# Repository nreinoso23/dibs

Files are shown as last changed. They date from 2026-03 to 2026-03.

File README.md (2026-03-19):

# Dibs — Smart Study Room Kiosk System

> **Automated room reservation management with real-time occupancy verification for NYU Dibner Library**

Dibs is a distributed IoT room management system that solves a simple but persistent problem: **nobody knows how many study rooms are actually being used at any given time.** Rooms get ghost-booked, stolen by people who never reserved, and there's zero accountability for no-shows.

This system pairs an outer kiosk (Raspberry Pi 5 with touchscreen, sensors, and physical buttons) with an inner occupancy module (ESP32-S3 with camera and LCD), all synchronized through Google Calendar API to a web booking interface — delivering real-time room status, automated check-in enforcement, and walk-in booking at **~$167 per unit** versus $749–$800+ for enterprise competitors.

Built as a Semester Long Design Project (SLDP) at NYU Tandon School of Engineering.

<p align="center">
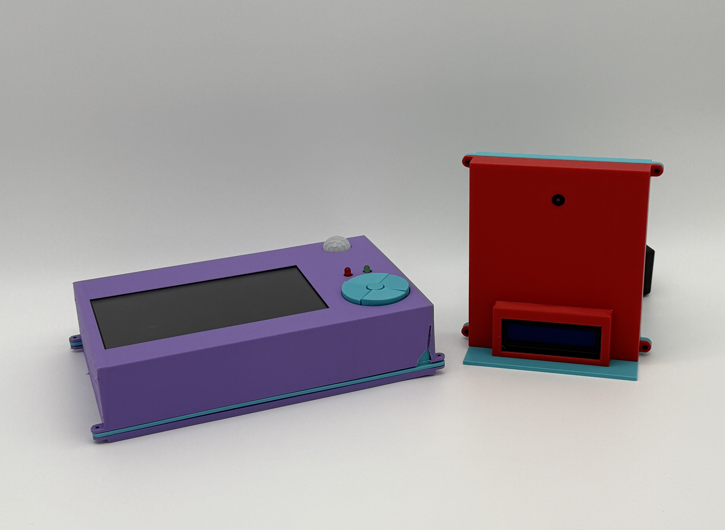
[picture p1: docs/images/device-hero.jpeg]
Dibs Kiosk System
  
</p>

<p align="center">
  <a href="https://youtu.be/KSitBOF_cG8">📺 Watch the full demo video</a>
</p>

---

## Table of Contents

- [Features](#features)
- [System Architecture](#system-architecture)
- [Hardware](#hardware)
- [Software Components](#software-components)
- [Room State Machine](#room-state-machine)
- [Tech Stack](#tech-stack)
- [Project Structure](#project-structure)
- [Setup & Installation](#setup--installation)
- [Configuration](#configuration)
- [How It Works](#how-it-works)
- [Competitive Analysis](#competitive-analysis)
- [Design Decisions & Tradeoffs](#design-decisions--tradeoffs)
- [Lessons Learned](#lessons-learned)
- [Future Improvements](#future-improvements)
- [Team](#team)

---

## Features

- **Real-time reservation display** — Shows current and upcoming bookings synced with Google Calendar
- **Walk-in booking** — 2-tap booking with dynamic duration limits based on next reservation and library hours
- **Check-in enforcement** — 10-minute check-in window with N-number authentication; no-shows auto-canceled
- **Occupancy verification** — Face detection via ESP32-CAM confirms room is actually in use
- **Physical button navigation** — Full GPIO-driven interface for accessible, touchscreen-free operation
- **Motion-activated display** — PIR sensor wakes screen on approach, sleeps after 30 seconds of inactivity
- **LED status indicators** — Green (available) / Red (occupied) visible from down the hallway
- **Context-aware LCD messaging** — Inner room display adapts messages based on face detection + room state
- **Adaptive polling** — Dynamic refresh rates (5–30s) based on proximity to check-in windows
- **Web + kiosk sync** — Bidirectional: bookings from either interface appear on both instantly

<p align="center">
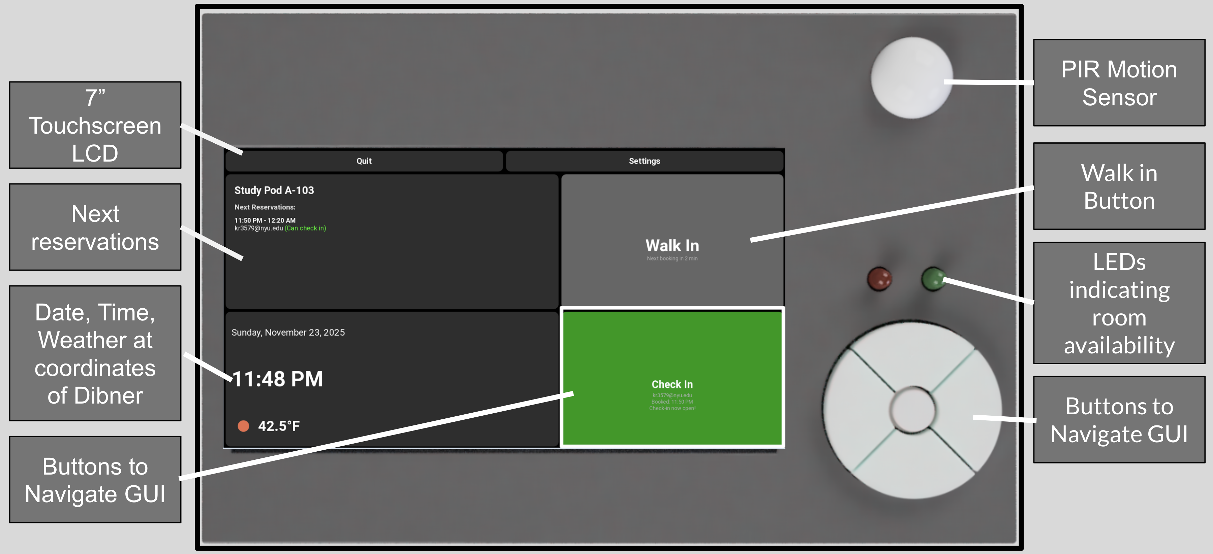
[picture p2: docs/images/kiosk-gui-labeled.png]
Kiosk GUI Interface
  
  <br>
  <em>Kiosk touchscreen interface with labeled components</em>
</p>

---

## System Architecture

```
┌──────────────────────────────────────────────────────────────────────┐
│                        RASPBERRY PI 5 (Outer Kiosk)                  │
│                                                                      │
│  ┌──────────────────┐  ┌──────────────────┐  ┌───────────────────┐  │
│  │  Main Kiosk GUI  │  │  Flask API Server │  │  Face Detection + │  │
│  │    (app.py)      │◄─│  (kiosk_api_     │◄─│  LCD Controller   │  │
│  │                  │  │   server.py)      │  │  (pi_cam_smart_  │  │
│  │  Kivy Framework  │  │                  │  │   lcd.py)         │  │
│  │  GPIO Buttons    │  │  /api/room_status │  │                  │  │
│  │  PIR Sensor      │  │  /api/health     │  │  OpenCV + cvzone  │  │
│  │  LED Control     │  │  /api/schedule   │  │  Headless mode    │  │
│  └──────────────────┘  └──────────────────┘  └────────┬──────────┘  │
│                                                        │             │
└────────────────────────────────────────────────────────┼─────────────┘
                                                         │
                                                   WiFi (HTTP)
                                                         │
┌────────────────────────────────────────────────────────┼─────────────┐
│                      ESP32-S3 CAM (Inner Module)       │             │
│                                                        │             │
│  ┌─────────────────────────────────────────────────────┘            │
│  │                                                                  │
│  │  Arduino Sketch (Station Mode)                                   │
│  │  - MJPEG Video Streaming (port 81)                               │
│  │  - HTTP endpoint for LCD text control (/lcd)                     │
│  │  - I2C 16x2 LCD Display Driver                                   │
│  │  - Connects to existing WiFi (not AP mode)                       │
│  │                                                                  │
└──────────────────────────────────────────────────────────────────────┘
                                    │
                            Google Calendar API
                                    │
┌───────────────────────────────────┼──────────────────────────────────┐
│                  Web Booking Interface (nyu-dibner-bookings.onrender.com)      │
│                  Built by Kashvi Rungta                                       │
│                  - Remote reservations                                        │
│                  - Same calendar as single source of truth                    │
└──────────────────────────────────────────────────────────────────────┘
```

---

## Hardware

### Outer Device (Mounted outside room door)

<p align="center">
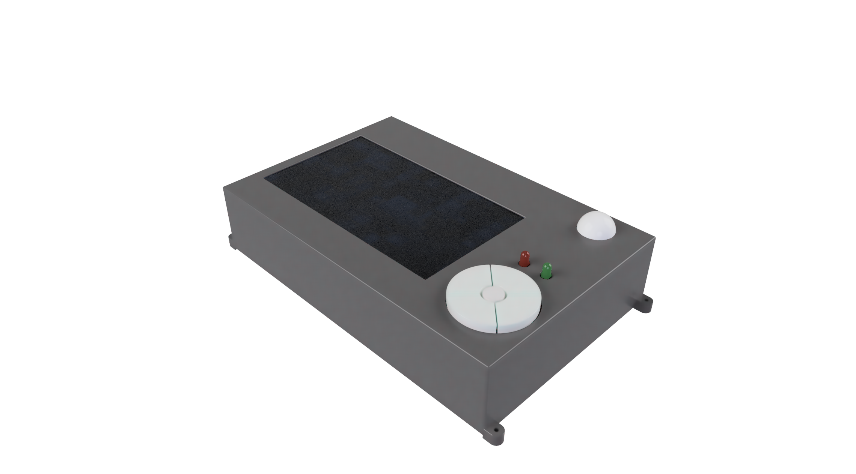
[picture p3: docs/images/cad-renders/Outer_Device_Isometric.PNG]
Outer Device CAD
  
</p>

| Component | Purpose |
|---|---|
| Raspberry Pi 5 | Main compute, runs GUI + API + face detection |
| 7" Touchscreen (1920×1080) | Primary display |
| 5× GPIO Buttons | UP, DOWN, LEFT, RIGHT, SELECT navigation |
| Walk-In Button | Dedicated physical button for walk-in bookings |
| PIR Motion Sensor (GPIO 14) | Screen wake/sleep on approach |
| Red LED (GPIO 9) | Room occupied indicator |
| Green LED (GPIO 11) | Room available indicator |

### Inner Device (Mounted inside room)

<p align="center">
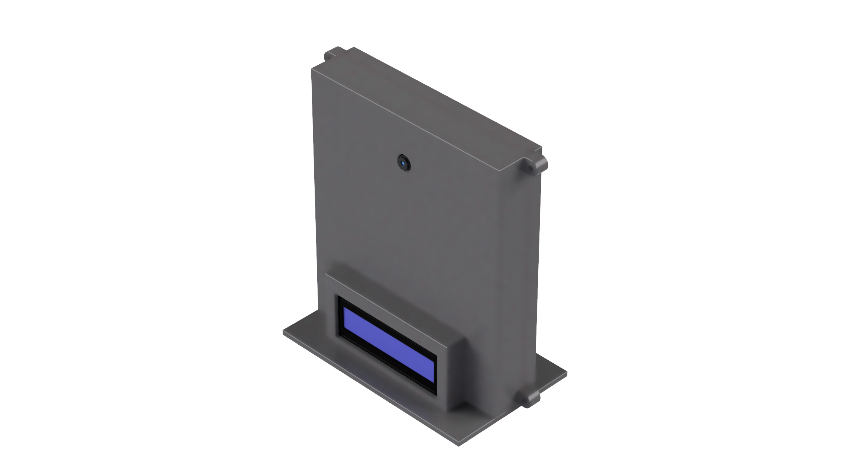
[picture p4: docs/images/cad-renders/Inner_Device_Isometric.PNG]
Inner Device CAD
  
</p>

| Component | Purpose |
|---|---|
| ESP32-S3 with Camera | Video streaming for face detection |
| 16×2 I2C LCD (GPIO 41 SDA, GPIO 42 SCL) | Context-aware room messages |

### Circuit Diagrams

<p align="center">
  <em>Outer Device</em><br>
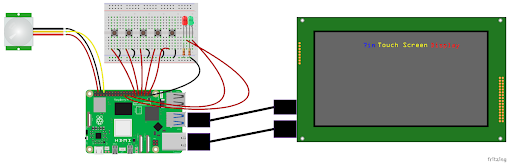
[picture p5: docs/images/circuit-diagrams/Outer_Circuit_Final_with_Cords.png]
Outer Device Circuit
  
</p>

<p align="center">
  <em>Inner Device</em><br>
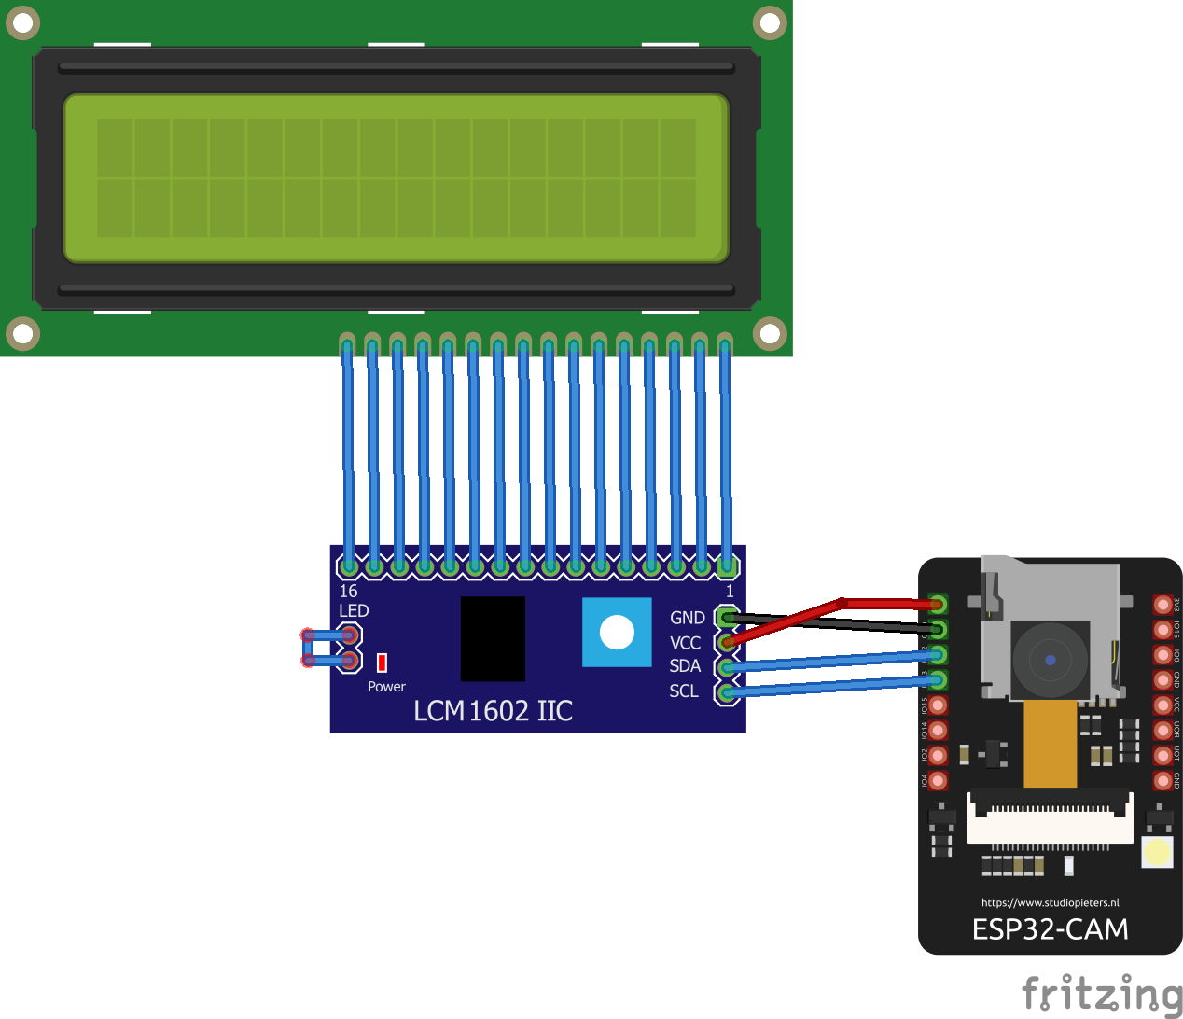
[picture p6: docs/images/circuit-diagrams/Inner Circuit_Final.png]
Inner Device Circuit
  
</p>

### Cost Comparison

| | Dibs | Logitech Tap Scheduler | Joan 6 RE |
|---|---|---|---|
| Hardware | **~$167** | $799 | $749 + $239 mount |
| Software/month | **$0** (edu/nonprofit) | $40/mo | $25/mo |
| Occupancy verification | **Yes** | No | No |
| Display | 1920×1080 | 1280×800 | 1024×758 |

---

## Software Components

### Raspberry Pi 5

| File | Purpose |
|---|---|
| `app.py` + `app.kv` | Main Kivy GUI application and layout |
| `reservation_manager_calendar.py` | Business logic: states, check-in, walk-in, cancellation |
| `google_calendar_client.py` | Google Calendar API wrapper with timezone handling |
| `kiosk_api_server.py` | Flask REST API bridging face detection ↔ reservation system |
| `gpio_handler.py` | Physical button input via GPIO interrupts |
| `focus_manager.py` | Semantic navigation grid system across 8+ screen types |
| `pir_handler.py` | Motion sensor → screen wake/sleep control |
| `led_status_handler.py` | LED color control based on room state |
| `pi_cam_smart_lcd.py` | Face detection + smart LCD message logic |
| `weather.py` | Open-Meteo API integration for local weather display |
| `clock.py` | Real-time clock widget |
| `scheduler.py` | Schedule display and check-in button widgets |
| `config.py` | Room name, calendar ID, credentials path, admin password |
| `kiosk_startup_kivy.py` | Boot sequence: prompts for ESP32 IP, launches all components |

### ESP32-S3

| File | Purpose |
|---|---|
| `Sketch_STATION_MODE.ino` | Main Arduino sketch: WiFi, streaming, LCD, HTTP endpoints |
| `app_httpd.cpp` | HTTP request handlers for stream + LCD + button endpoints |
| `camera_pins.h` | Pin definitions for ESP32-S3-EYE camera model |

---

## Room State Machine

```
                    ┌──────────────┐
        ┌──────────│  AVAILABLE   │◄──────────┐
        │          │  (Green LED) │           │
        │          └──────┬───────┘           │
        │                 │                    │
        │    Reservation within 10 min         │  Booking ends
        │                 │                    │  or no-show canceled
        │                 ▼                    │
        │          ┌──────────────┐           │
        │          │  CHECK-IN    │───────────┘
        │          │   READY      │  (10 min, no check-in → auto-cancel)
        │          │  (Red LED)   │
        │          └──────┬───────┘
        │                 │
        │          User checks in
        │          (N-number validated)
        │                 │
        │                 ▼
        │          ┌──────────────┐
        └──────────│   OCCUPIED   │
   Walk-in ends    │  (Red LED)   │
                   └──────────────┘
```

---

## Tech Stack

**Languages:** Python 3, C++ (Arduino)

**Raspberry Pi Libraries:**
- `kivy` — Touchscreen GUI framework
- `flask` — REST API server
- `opencv-python` + `cvzone` — Face detection
- `google-api-python-client` + `google-auth` — Calendar API
- `RPi.GPIO` — Button, LED, PIR sensor control
- `requests` — HTTP communication to ESP32
- `pytz` — Timezone handling (UTC ↔ America/New_York)

**ESP32 Libraries:**
- `WiFi.h` — Station Mode networking
- `esp_camera.h` — Camera initialization and streaming
- `LiquidCrystal_I2C` — 16×2 LCD display driver

**Infrastructure:**
- Google Calendar API — Single source of truth for all reservations
- Render — Web booking interface hosting ([nyu-dibner-bookings.onrender.com](https://nyu-dibner-bookings.onrender.com/))
- Open-Meteo API — Weather data

---

## Project Structure

```
dibs/
├── README.md
├── LICENSE
│
├── kiosk/                          # Raspberry Pi 5 application
│   ├── app.py                      # Main Kivy application entry point
│   ├── app.kv                      # Kivy UI layout definitions
│   ├── reservation_manager_calendar.py  # Reservation business logic
│   ├── google_calendar_client.py   # Google Calendar API wrapper
│   ├── kiosk_api_server.py         # Flask REST API server
│   ├── gpio_handler.py             # Physical button input handling
│   ├── focus_manager.py            # Semantic navigation grid system
│   ├── pir_handler.py              # PIR motion sensor → screen control
│   ├── led_status_handler.py       # LED status indicator control
│   ├── weather.py                  # Weather API integration
│   ├── clock.py                    # Real-time clock widget
│   ├── scheduler.py                # Schedule display widgets
│   ├── config.py                   # System configuration
│   ├── kiosk_startup_kivy.py       # Boot launcher with ESP32 IP prompt
│   ├── run_gui_fullscreen.sh       # Fullscreen launch wrapper
│   └── requirements.txt            # Python dependencies
│
├── esp32/                          # ESP32-S3 firmware
│   └── Sketch_STATION_MODE/
│       ├── Sketch_STATION_MODE.ino # Main Arduino sketch
│       ├── app_httpd.cpp           # HTTP endpoint handlers
│       └── camera_pins.h           # Pin definitions
│
├── face-detection/                 # Occupancy detection (runs on Pi)
│   ├── pi_cam_smart_lcd.py         # Face detection + LCD message logic
│   └── requirements.txt            # OpenCV dependencies
│
├── web/                            # Web booking interface (deployed on Render, built by Kashvi Rungta)
│   └── ...                         # See: https://nyu-dibner-bookings.onrender.com/
│
├── enclosures/                     # Hardware design files
│   ├── outer_device.step           # Outer kiosk CAD model
│   └── inner_device.step           # Inner camera module CAD model
│
├── docs/                           # Documentation
│   ├── ARCHITECTURE.md             # Detailed system architecture
│   ├── SETUP_GUIDE.md              # Step-by-step installation
│   ├── WIRING.md                   # GPIO pin assignments + wiring diagram
│   ├── SOFTWARE_SETUP.md           # Software dependencies + configuration
│   └── images/                     # Architecture diagrams, photos, screenshots
│       ├── system_architecture.png
│       ├── state_machine.png
│       ├── outer_device_cad.png
│       ├── inner_device_cad.png
│       ├── kiosk_main_screen.png
│       ├── kiosk_checkin_screen.png
│       └── kiosk_walkin_screen.png
│
├── autostart/                      # Deployment configuration
│   └── kiosk-startup.desktop       # Linux autostart entry
│
└── .gitignore
```

---

## Setup & Installation

### Prerequisites

- Raspberry Pi 5 with Raspberry Pi OS (Wayland)
- ESP32-S3 with camera module (ESP32-S3-EYE or equivalent)
- 7" touchscreen display (1920×1080)
- PIR motion sensor, LEDs, GPIO push buttons
- Google Cloud service account with Calendar API enabled

### Raspberry Pi Setup

```bash
# Clone the repository
git clone https://github.com/yourusername/dibs.git
cd dibs

# Install Python dependencies
pip install kivy flask google-api-python-client google-auth pytz requests --break-system-packages

# Install OpenCV (in virtual environment recommended)
cd face-detection
python3 -m venv venv
source venv/bin/activate
pip install opencv-python cvzone requests

# Configure
cp kiosk/config.py.example kiosk/config.py
# Edit config.py with your calendar ID, room name, and credentials path
```

### ESP32-S3 Setup

1. Open `esp32/Sketch_STATION_MODE/Sketch_STATION_MODE.ino` in Arduino IDE
2. Update WiFi credentials (`ssid` and `password`)
3. Verify I2C LCD address (default: `0x27`)
4. Upload to ESP32-S3

### Running

```bash
# Option 1: Automated startup
python3 kiosk/kiosk_startup_kivy.py

# Option 2: Manual (3 terminals)
# Terminal 1: API server
python3 kiosk/kiosk_api_server.py

# Terminal 2: Face detection
cd face-detection && source venv/bin/activate
python3 pi_cam_smart_lcd.py --ip <ESP32_IP>

# Terminal 3: Main GUI
cd kiosk && python3 app.py
```

### Autostart on Boot

```bash
cp autostart/kiosk-startup.desktop ~/.config/autostart/
# Edit Exec path if needed
```

---

## Configuration

Edit `kiosk/config.py`:

```python
CALENDAR_CONFIG = {
    'credentials_file': 'key.json',       # Google service account key
    'calendar_id': 'your_calendar@group.calendar.google.com',
    'room_name': 'Study Room LC416',      # Must match web booking format
}

LIBRARY_HOURS = {
    'open': '07:00',    # 7 AM
    'close': '01:00',   # 1 AM (next day)
}

CHECK_IN_WINDOW_MINUTES = 10    # Minutes before start time to allow check-in
NO_SHOW_CANCEL_MINUTES = 10     # Minutes after start to cancel if not checked in
```

---

## How It Works

### Walk-In Flow
1. User approaches kiosk → PIR sensor wakes screen
2. User taps "Walk In" (or presses button) → Duration selection screen
3. User selects duration (limited by next reservation / library close)
4. Booking created in Google Calendar with `isWalkIn=true` and `checkedIn=true`
5. Walk-ins are **immune to no-show cancellation** — the act of walking in is the check-in

### Check-In Flow
1. Reservation starts within 10 minutes → Check-In button turns green
2. Walk-In button simultaneously disables (mutual exclusivity)
3. User enters 9-digit N-number → System validates against booking's `bookedBy` field
4. Google Calendar event updated with `checkedIn=true` and timestamp
5. If no check-in within 10 minutes after start → booking auto-deleted

### Occupancy Detection
1. ESP32-S3 streams MJPEG video on port 81
2. Pi runs OpenCV face detection on the stream (headless, no GUI window)
3. Face count + room state from API → context-aware LCD messages
4. LCD only updates when state changes (prevents visual flickering)

---

## Design Decisions & Tradeoffs

| Decision | Chosen | Alternative | Why |
|---|---|---|---|
| ESP32 network mode | **Station Mode** (connects to router) | Access Point (creates own network) | AP mode caused streaming lag; Station offloads networking to router |
| Data storage | **Google Calendar API** (cloud) | Local SQLite | Enables sync between kiosk and web interface; single source of truth |
| Navigation | **GPIO buttons + touchscreen** | Touchscreen only | Physical buttons provide accessible, reliable input; work even if touchscreen fails |
| Face detection compute | **Raspberry Pi** (edge) | ESP32 on-device | ESP32 lacks compute for real-time CV; Pi handles OpenCV efficiently |
| Polling strategy | **Adaptive (5–30s)** | Fixed interval | Saves API calls during idle; responsive during critical check-in windows |
| Walk-in check-in | **Atomic at creation** | Separate check-in step | Prevents race condition with no-show cancellation policy |

---

## Lessons Learned

- **Distributed systems fail at boundaries.** Timezone mismatches (UTC vs. Eastern) silently broke calendar queries for days before we caught it. Always normalize timezones explicitly.
- **Network mode matters more than you'd think.** The ESP32 in AP mode worked in testing but introduced unacceptable streaming lag under real conditions. Switching to Station Mode eliminated the issue entirely.
- **State tracking prevents noise.** Without tracking previous LCD state, the display was constantly refreshing with the same message, creating a distracting flicker. Only updating on state changes made the system feel polished.
- **Adaptive behavior beats fixed intervals.** A flat 30-second polling interval was too slow during check-in windows and wastefully fast during idle periods. Dynamic rates (5s critical, 30s idle) balanced responsiveness with API efficiency.
- **Wayland breaks assumptions.** Standard Linux display tools (`scrot`, `vcgencmd`) don't work on Wayland. Had to switch to `grim` for screenshots and overlay-based approaches for screen control.

---

## Future Improvements

- Real-time room availability dashboard for library staff
- Shorter focal length camera for better face detection in small rooms
- Email/push reminders before reservation start
- RFID/NFC card tap for faster check-in
- Open-source release with deployment documentation
- Multi-room management dashboard

---

## Team

**PR&R Solutions** — NYU Tandon School of Engineering, SLDP 2025

| Name | Role | Major |
|---|---|---|
| Nicholas Reinoso | Embedded systems, software development, CAD enclosure design, protoboard layout, computer vision, API integration | B.S. Electrical and Computer Engineering |
| Kashvi Rungta | Web booking interface and Pi integration ([nyu-dibner-bookings.onrender.com](https://nyu-dibner-bookings.onrender.com/)) | B.S. Computer Science |
| Jiya Patel | Project coordination and documentation support | B.S. Mechanical Engineering |

---

## License

This project is licensed under the MIT License — see [LICENSE](LICENSE) for details.

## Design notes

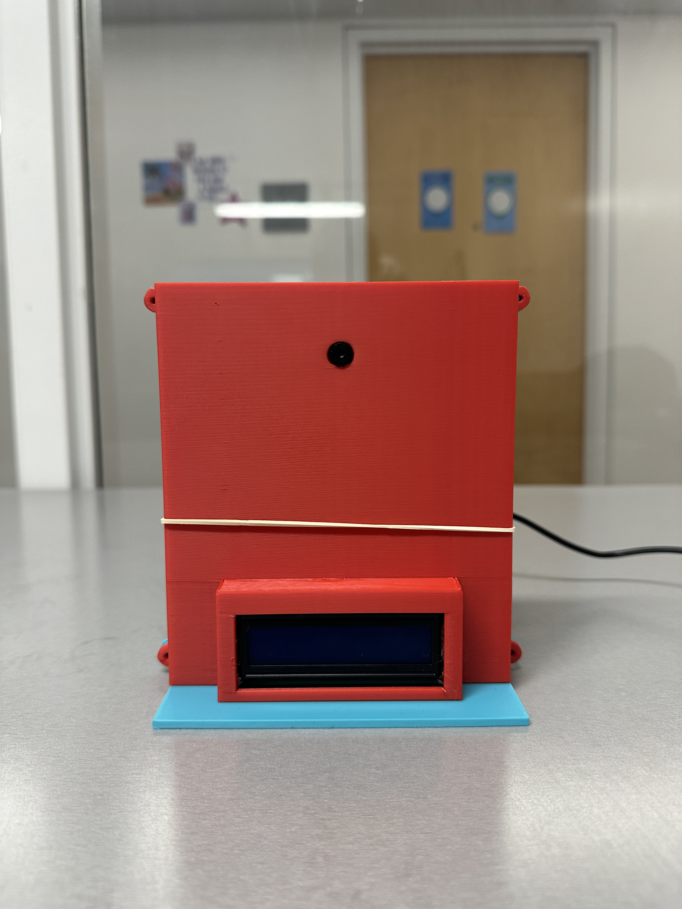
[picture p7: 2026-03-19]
docs/images/hardware/Inner_Device_Front.JPG

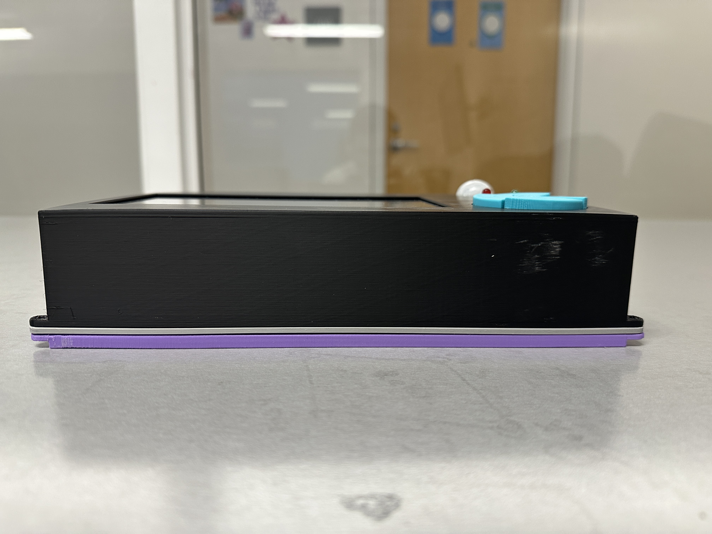
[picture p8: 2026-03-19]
docs/images/hardware/Outer_Device_Front.JPG

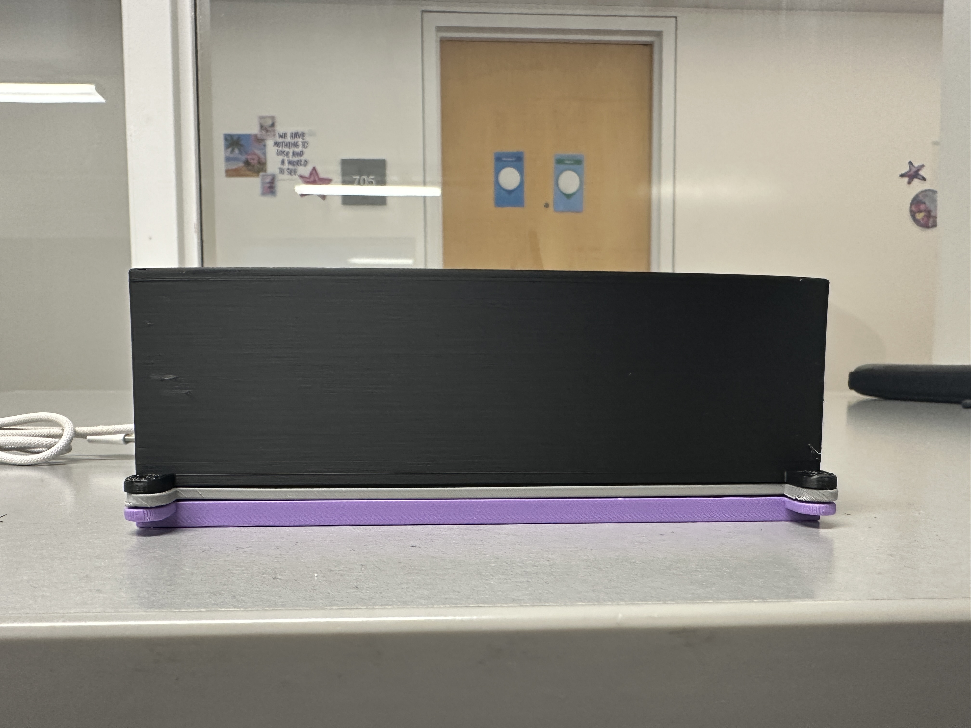
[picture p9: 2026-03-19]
docs/images/hardware/Outer_Device_Left.JPG

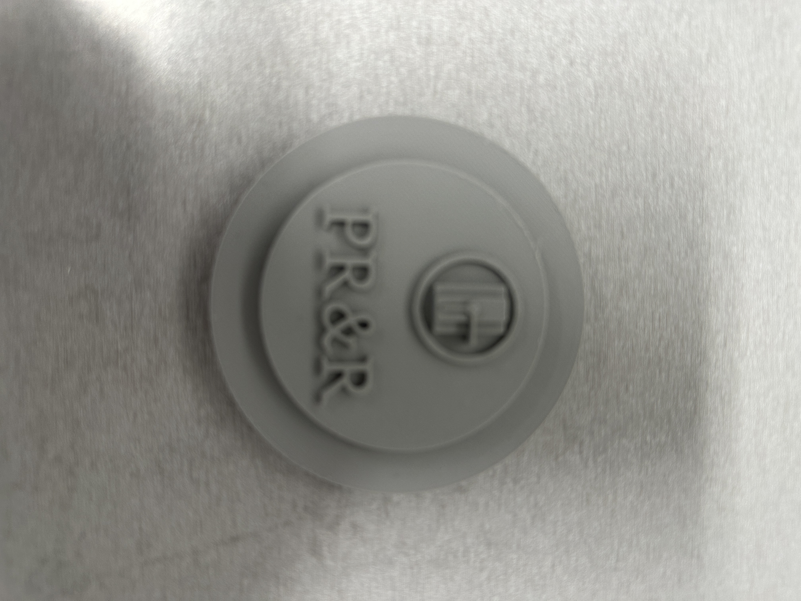
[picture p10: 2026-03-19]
docs/images/hardware/Emblem_Photo.JPG

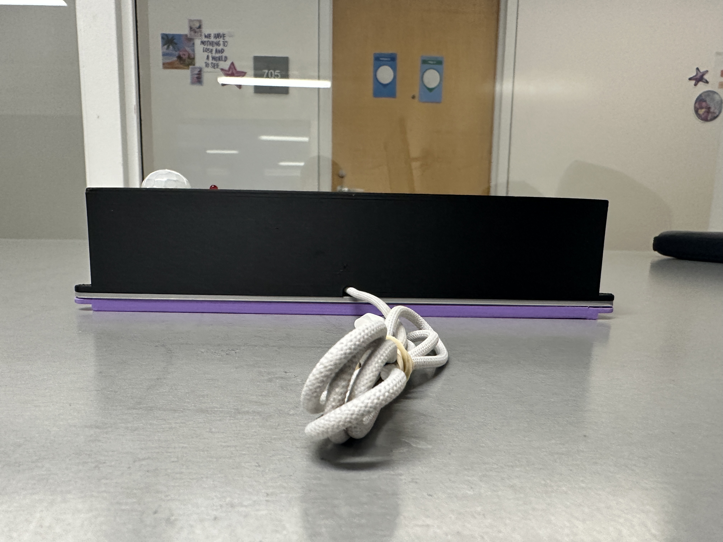
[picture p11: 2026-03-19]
docs/images/hardware/Outer_Device_Back.JPG

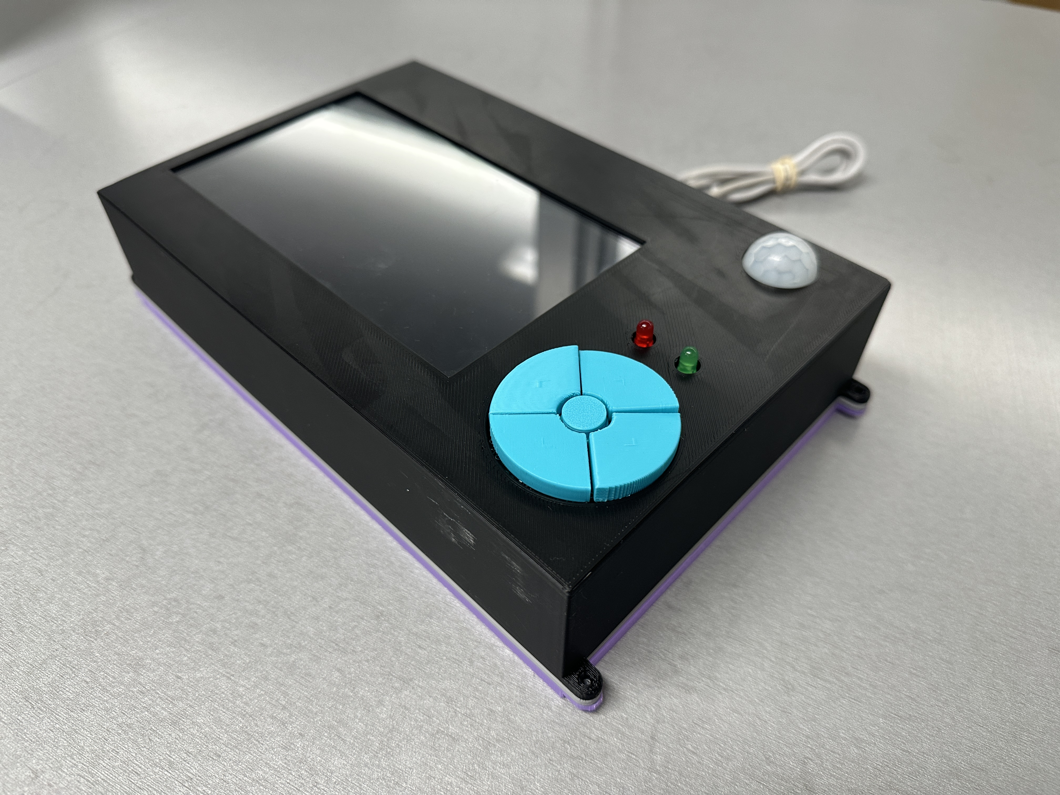
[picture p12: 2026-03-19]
docs/images/hardware/Outer_Device_Front_Isometric.JPG

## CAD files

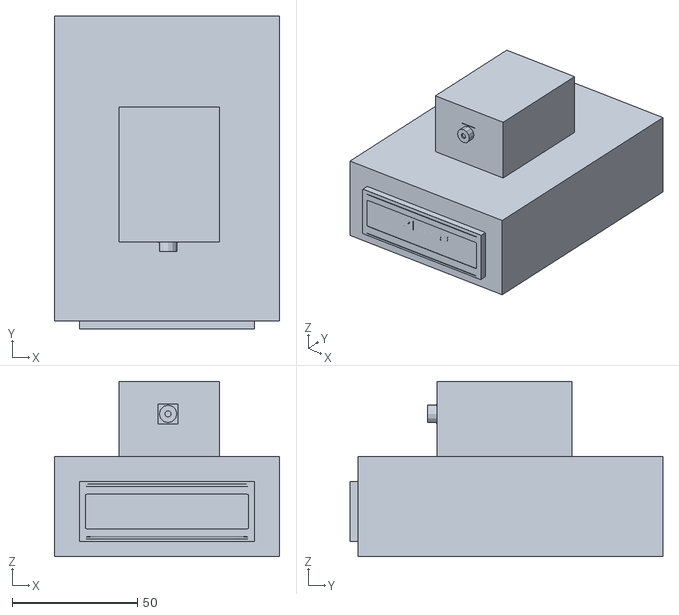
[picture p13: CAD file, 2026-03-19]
docs/hardware/Tinkercad_Inner Device.stl
90.0 x 125.0 x 70.0

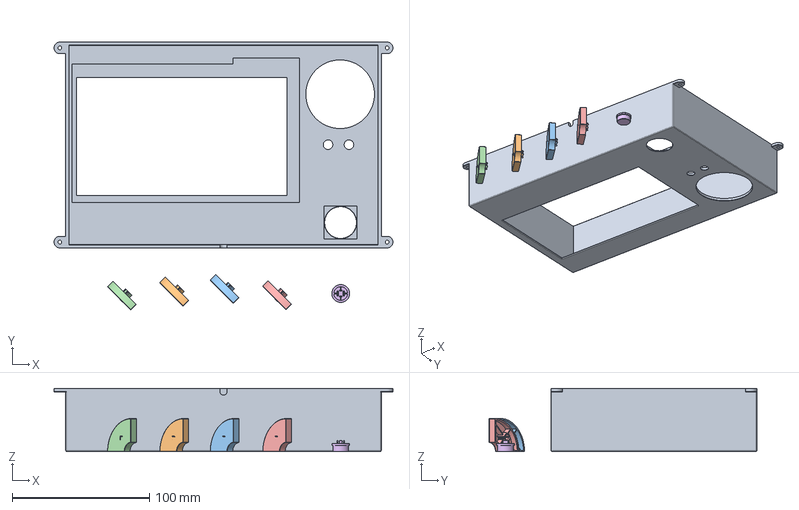
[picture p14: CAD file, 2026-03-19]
enclosures/Outer_Cover.3mf
247.0 x 195.2 x 46.1 mm
Outer_Cover

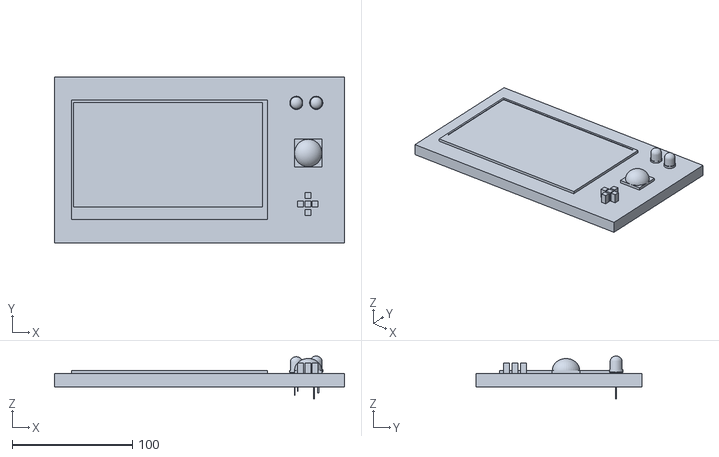
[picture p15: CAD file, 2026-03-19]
docs/hardware/Tinkercad_Outer Device.stl
241.0 x 138.0 x 35.6

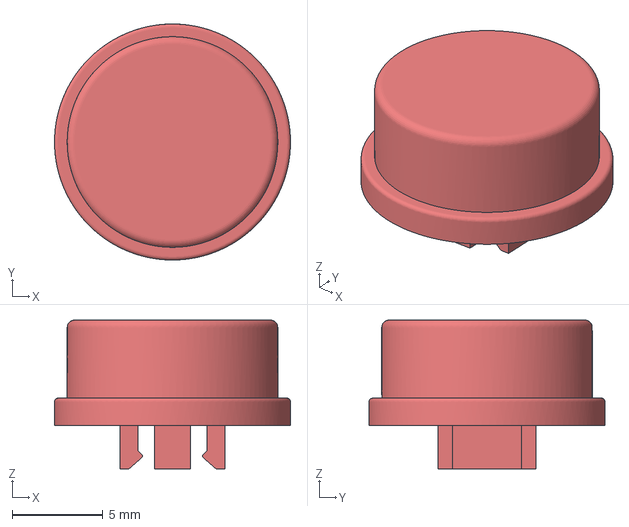
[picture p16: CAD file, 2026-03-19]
enclosures/12mm Push Button Cap.3mf
13.0 x 13.0 x 8.20 mm

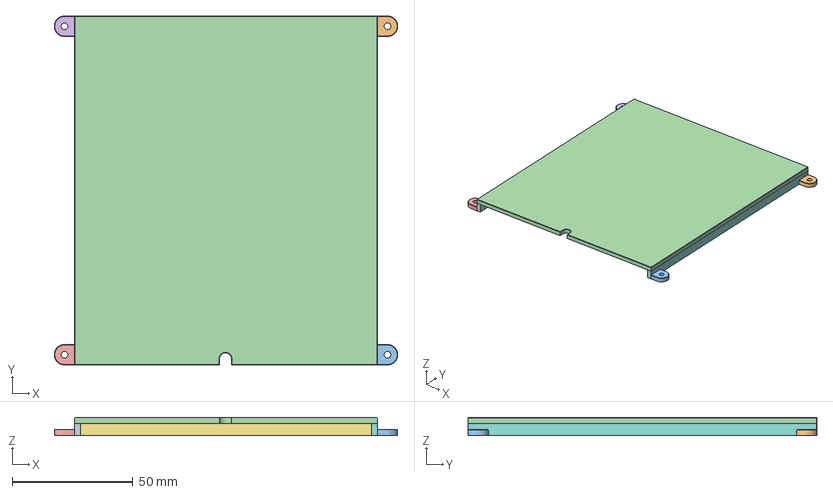
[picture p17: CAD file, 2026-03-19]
enclosures/Inner_Back.3mf
142.5 x 144.7 x 7.50 mm

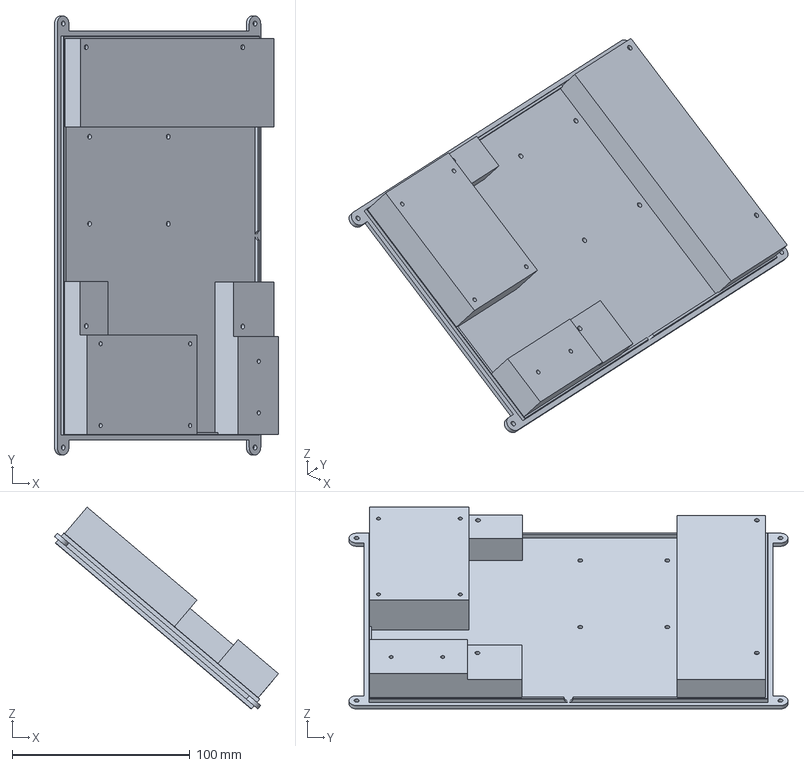
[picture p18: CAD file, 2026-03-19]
enclosures/Outer_Mount.3mf
126.0 x 247.0 x 113.6 mm

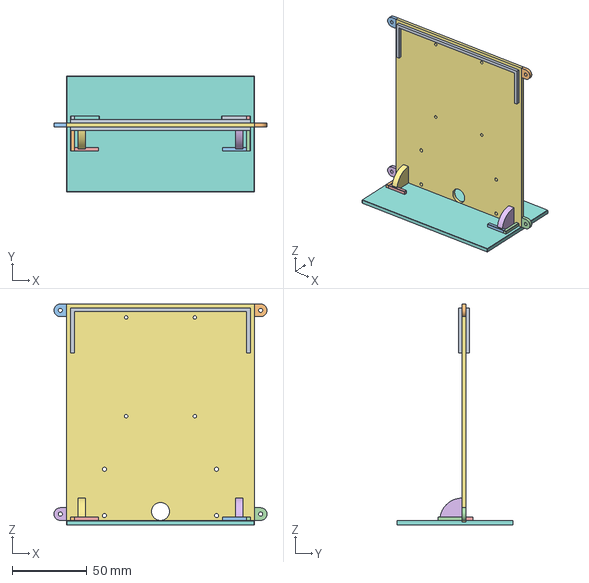
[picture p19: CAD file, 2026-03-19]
enclosures/Inner_Base.3mf
142.5 x 77.6 x 147.8 mm

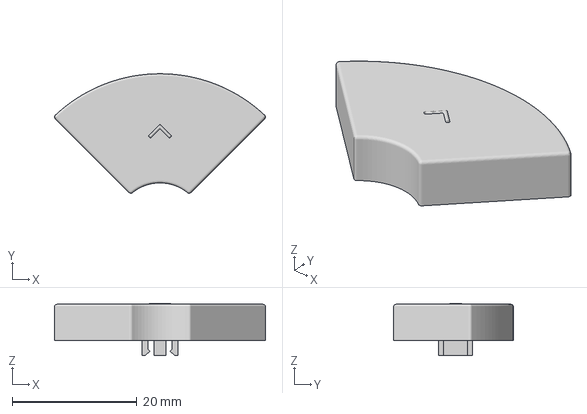
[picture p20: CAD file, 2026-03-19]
enclosures/Rounded Button.3mf
33.8 x 19.2 x 8.36 mm

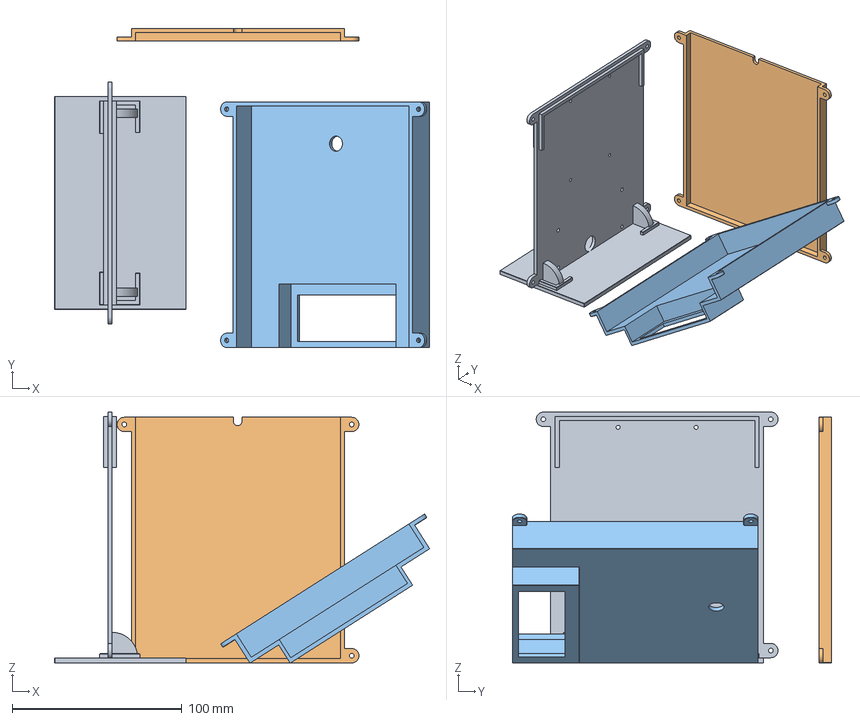
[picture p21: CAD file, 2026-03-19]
enclosures/Inner_Front_Mount.3mf
220.9 x 188.1 x 147.8 mm
Inner_Base
Inner_Back
Inner_Front_Mount

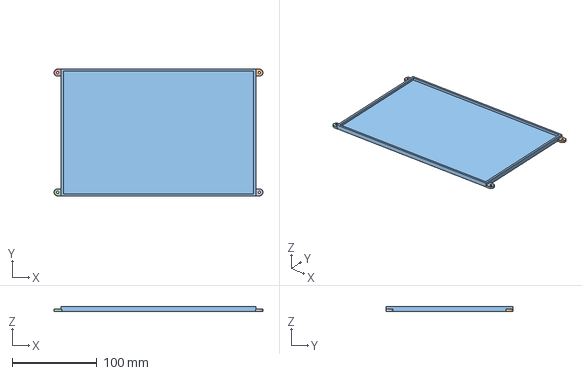
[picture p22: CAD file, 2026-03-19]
enclosures/Outer_Back.3mf
247.0 x 150.0 x 5.50 mm

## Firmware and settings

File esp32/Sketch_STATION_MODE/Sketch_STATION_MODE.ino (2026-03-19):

/**********************************************************************
  Filename    : Video Web Server STATION MODE - QVGA Version
  Description : Connects to existing WiFi router instead of creating AP
               Much more stable and faster than AP mode!
  Resolution  : QVGA (320x240) for speed
  Modified    : 2025/11/14
**********************************************************************/
#include "esp_camera.h"
#include <WiFi.h>
#include "sd_read_write.h"
#include <Wire.h>
#include <LiquidCrystal_I2C.h>

// Select camera model
#define CAMERA_MODEL_ESP32S3_EYE

#define SERIAL_PORT Serial0

#include "camera_pins.h"

// WiFi credentials - CHANGE THESE to your router!
const char* ssid = "nyu-android";         // ← Change this!
const char* password = "YOUR_WIFI_PASSWORD"; // ← Change this!

// I2C LCD Configuration
#define LCD_ADDRESS 0x27
#define LCD_COLUMNS 16
#define LCD_ROWS 2
#define I2C_SDA 41
#define I2C_SCL 42

LiquidCrystal_I2C lcd(LCD_ADDRESS, LCD_COLUMNS, LCD_ROWS);

// Track backlight state
bool lcdBacklightOn = true;

void cameraInit(void);
void startCameraServer();
void lcdInit(void);

void setup() {
  SERIAL_PORT.begin(115200);
  delay(1000);
  SERIAL_PORT.println("\n\nBooting camera server (STATION MODE)...");

  // Initialize I2C LCD
  lcdInit();
  lcd.clear();
  lcd.setCursor(0, 0);
  lcd.print("Initializing...");

  // Initialize camera
  cameraInit();
  
  // Initialize SD card (optional - comment out if causing issues)
  sdmmcInit();
  removeDir(SD_MMC, "/video");
  createDir(SD_MMC, "/video");
  
  // Connect to WiFi Router (STATION MODE)
  SERIAL_PORT.println("Connecting to WiFi...");
  lcd.clear();
  lcd.setCursor(0, 0);
  lcd.print("Connecting WiFi");
  
  WiFi.mode(WIFI_STA);  // Station mode (not AP!)
  WiFi.begin(ssid, password);
  
  int attempts = 0;
  while (WiFi.status() != WL_CONNECTED && attempts < 20) {
    delay(500);
    SERIAL_PORT.print(".");
    lcd.setCursor(attempts % 16, 1);
    lcd.print(".");
    attempts++;
  }
  
  if (WiFi.status() != WL_CONNECTED) {
    SERIAL_PORT.println("\nFailed to connect to WiFi!");
    lcd.clear();
    lcd.setCursor(0, 0);
    lcd.print("WiFi Failed!");
    lcd.setCursor(0, 1);
    lcd.print("Check settings");
    return;
  }
  
  SERIAL_PORT.println("\nWiFi connected!");
  IPAddress IP = WiFi.localIP();
  SERIAL_PORT.print("IP address: ");
  SERIAL_PORT.println(IP);
  
  // Display on LCD
  lcd.clear();
  lcd.setCursor(0, 0);
  lcd.print("Connected!");
  lcd.setCursor(0, 1);
  lcd.print(IP);

  // Start camera server
  startCameraServer();

  SERIAL_PORT.println("\n========================================");
  SERIAL_PORT.println("Camera Ready! STATION MODE (QVGA)");
  SERIAL_PORT.println("========================================");
  SERIAL_PORT.print("Stream URL: http://");
  SERIAL_PORT.print(IP);
  SERIAL_PORT.println(":81/stream");
  SERIAL_PORT.print("Web interface: http://");
  SERIAL_PORT.println(IP);
  SERIAL_PORT.println("========================================\n");
}

void loop() {
  // Monitor connection
  if (WiFi.status() != WL_CONNECTED) {
    SERIAL_PORT.println("WiFi connection lost! Reconnecting...");
    lcd.clear();
    lcd.setCursor(0, 0);
    lcd.print("Reconnecting...");
    WiFi.reconnect();
  }
  delay(10000);
}

void lcdInit(void) {
  SERIAL_PORT.println("Starting LCD initialization...");
  Wire.begin(I2C_SDA, I2C_SCL);
  delay(100);
  
  lcd.init();
  lcd.backlight();
  lcdBacklightOn = true;
  delay(100);
  
  SERIAL_PORT.println("LCD initialized!");
}

void cameraInit(void){
  camera_config_t config;
  config.ledc_channel = LEDC_CHANNEL_0;
  config.ledc_timer = LEDC_TIMER_0;
  config.pin_d0 = Y2_GPIO_NUM;
  config.pin_d1 = Y3_GPIO_NUM;
  config.pin_d2 = Y4_GPIO_NUM;
  config.pin_d3 = Y5_GPIO_NUM;
  config.pin_d4 = Y6_GPIO_NUM;
  config.pin_d5 = Y7_GPIO_NUM;
  config.pin_d6 = Y8_GPIO_NUM;
  config.pin_d7 = Y9_GPIO_NUM;
  config.pin_xclk = XCLK_GPIO_NUM;
  config.pin_pclk = PCLK_GPIO_NUM;
  config.pin_vsync = VSYNC_GPIO_NUM;
  config.pin_href = HREF_GPIO_NUM;
  config.pin_sccb_sda = SIOD_GPIO_NUM;
  config.pin_sccb_scl = SIOC_GPIO_NUM;
  config.pin_pwdn = PWDN_GPIO_NUM;
  config.pin_reset = RESET_GPIO_NUM;
  config.xclk_freq_hz = 10000000;
  
  // QVGA for maximum speed and stability
  config.frame_size = FRAMESIZE_QVGA;    // 320x240
  config.pixel_format = PIXFORMAT_JPEG;
  config.grab_mode = CAMERA_GRAB_LATEST;
  config.fb_location = CAMERA_FB_IN_PSRAM;
  config.jpeg_quality = 20;
  config.fb_count = 2;
  
  if(psramFound()){
    SERIAL_PORT.println("PSRAM found - optimized settings active");
  } else {
    SERIAL_PORT.println("WARNING: No PSRAM!");
    config.fb_location = CAMERA_FB_IN_DRAM;
    config.fb_count = 1;
  }

  esp_err_t err = esp_camera_init(&config);
  if (err != ESP_OK) {
    SERIAL_PORT.printf("Camera init failed: 0x%x\n", err);
    lcd.clear();
    lcd.print("Camera FAILED!");
    return;
  }

  sensor_t * s = esp_camera_sensor_get();
  s->set_vflip(s, 1);
  s->set_brightness(s, 1);
  s->set_saturation(s, 0);
  
  SERIAL_PORT.println("Camera initialized - QVGA mode!");
}

void updateLCD(const char* line1, const char* line2) {
  // Write line1 character by character, pad with spaces
  lcd.setCursor(0, 0);
  for (int i = 0; i < 16; i++) {
    if (line1[i] != '\0') {
      lcd.write(line1[i]);
    } else {
      // Once we hit null, pad rest with spaces
      for (int j = i; j < 16; j++) {
        lcd.write(' ');
      }
      break;
    }
  }
  
  // Write line2 character by character, pad with spaces
  lcd.setCursor(0, 1);
  for (int i = 0; i < 16; i++) {
    if (line2[i] != '\0') {
      lcd.write(line2[i]);
    } else {
      // Once we hit null, pad rest with spaces
      for (int j = i; j < 16; j++) {
        lcd.write(' ');
      }
      break;
    }
  }
}

// Control LCD backlight on/off
void setLCDBacklight(bool on) {
  if (on && !lcdBacklightOn) {
    lcd.backlight();
    lcdBacklightOn = true;
    SERIAL_PORT.println("LCD backlight ON");
  } else if (!on && lcdBacklightOn) {
    lcd.noBacklight();
    lcdBacklightOn = false;
    SERIAL_PORT.println("LCD backlight OFF");
  }
}

// Get current backlight state
bool getLCDBacklightState() {
  return lcdBacklightOn;
}

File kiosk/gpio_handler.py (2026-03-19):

"""
GPIO Button Handler for Raspberry Pi Kiosk
Maps physical buttons to GUI navigation
"""
from gpiozero import Button
from kivy.clock import Clock
from kivy.logger import Logger
import time


class GPIOHandler:
    """Handle GPIO button inputs for kiosk navigation"""
    
    # GPIO Pin assignments
    PIN_DOWN = 5
    PIN_LEFT = 6
    PIN_RIGHT = 13
    PIN_SELECT = 19
    PIN_UP = 26
    
    def __init__(self, app):
        """Initialize GPIO buttons
        
        Args:
            app: Reference to the Kivy app instance
        """
        self.app = app
        self.buttons = {}
        self.focus_manager = None  # Will be set by app
        
        # Track last button press time for additional software debouncing
        self.last_button_time = {}
        self.debounce_delay = 0.15  # 150ms minimum between button presses
        
        try:
            # Initialize buttons with pull-up resistors and increased bounce time
            self.buttons['down'] = Button(self.PIN_DOWN, pull_up=True, bounce_time=0.15)
            self.buttons['left'] = Button(self.PIN_LEFT, pull_up=True, bounce_time=0.15)
            self.buttons['right'] = Button(self.PIN_RIGHT, pull_up=True, bounce_time=0.15)
            self.buttons['select'] = Button(self.PIN_SELECT, pull_up=True, bounce_time=0.15)
            self.buttons['up'] = Button(self.PIN_UP, pull_up=True, bounce_time=0.15)
            
            # Bind button press events
            self.buttons['down'].when_pressed = self.on_down
            self.buttons['left'].when_pressed = self.on_left
            self.buttons['right'].when_pressed = self.on_right
            self.buttons['select'].when_pressed = self.on_select
            self.buttons['up'].when_pressed = self.on_up
            
            Logger.info("GPIOHandler: Buttons initialized successfully")
            
        except Exception as e:
            Logger.error(f"GPIOHandler: Failed to initialize buttons: {e}")
    
    def is_debounced(self, button_name):
        """Check if enough time has passed since last button press"""
        current_time = time.time()
        if button_name in self.last_button_time:
            time_since_last = current_time - self.last_button_time[button_name]
            if time_since_last < self.debounce_delay:
                Logger.info(f"GPIOHandler: {button_name} debounced (only {time_since_last*1000:.1f}ms since last press)")
                return False
        self.last_button_time[button_name] = current_time
        return True
    
    def schedule_on_main_thread(self, callback):
        """Schedule callback to run on Kivy's main thread"""
        Clock.schedule_once(lambda dt: callback(), 0)
    
    def on_down(self):
        """Handle DOWN button press"""
        if not self.is_debounced('down'):
            return
        Logger.info("GPIOHandler: DOWN pressed")
        self.schedule_on_main_thread(self.handle_down)
    
    def on_up(self):
        """Handle UP button press"""
        if not self.is_debounced('up'):
            return
        Logger.info("GPIOHandler: UP pressed")
        self.schedule_on_main_thread(self.handle_up)
    
    def on_left(self):
        """Handle LEFT button press"""
        if not self.is_debounced('left'):
            return
        Logger.info("GPIOHandler: LEFT pressed")
        self.schedule_on_main_thread(self.handle_left)
    
    def on_right(self):
        """Handle RIGHT button press"""
        if not self.is_debounced('right'):
            return
        Logger.info("GPIOHandler: RIGHT pressed")
        self.schedule_on_main_thread(self.handle_right)
    
    def on_select(self):
        """Handle SELECT button press"""
        if not self.is_debounced('select'):
            return
        Logger.info("GPIOHandler: SELECT pressed")
        self.schedule_on_main_thread(self.handle_select)
    
    # Navigation handlers
    def handle_down(self):
        """DOWN button - move focus down"""
        if self.focus_manager:
            self.focus_manager.move_focus_down()
    
    def handle_up(self):
        """UP button - move focus up"""
        if self.focus_manager:
            self.focus_manager.move_focus_up()
    
    def handle_left(self):
        """LEFT button - move focus left or go back"""
        if self.focus_manager:
            self.focus_manager.move_focus_left()
    
    def handle_right(self):
        """RIGHT button - move focus right"""
        if self.focus_manager:
            self.focus_manager.move_focus_right()
    
    def handle_select(self):
        """SELECT button - activate focused widget"""
        if self.focus_manager:
            self.focus_manager.activate_focused()
    
    def cleanup(self):
        """Clean up GPIO resources"""
        try:
            for button in self.buttons.values():
                button.close()
            Logger.info("GPIOHandler: Cleaned up GPIO resources")
        except Exception as e:
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

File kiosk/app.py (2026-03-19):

from kivy.app import App
from kivy.lang import Builder
from kivy.uix.screenmanager import ScreenManager, Screen
from kivy.logger import Logger
from kivy.properties import StringProperty, NumericProperty, BooleanProperty
from kivy.clock import Clock
import logging
from kivy.uix.widget import Widget
from kivy.graphics import RoundedRectangle, Color
from rounded import RoundedRectangleContainer
from weather import WeatherWidget
from reservation_manager_calendar import ReservationManager
from config import CALENDAR_CONFIG
import platform
from datetime import datetime, timedelta

# Import GPIO handler only on Raspberry Pi
try:
    from gpio_handler import GPIOHandler
    from focus_manager import FocusManager
    from pir_handler import PIRHandler
    from led_status_handler import LEDStatusHandler
    GPIO_AVAILABLE = True
except ImportError:
    GPIO_AVAILABLE = False
    Logger.warning("TestApp: GPIO not available - running without physical buttons")

Logger.setLevel(level='INFO')
logging.basicConfig(level=logging.WARNING)

import kivy

kivy.config.Config.set('kivy', 'log_level', 'warning')
kivy.config.Config.write()
kivy.config.Config.set('graphics', 'borderless', '1')
kivy.config.Config.set('graphics', 'fullscreen', '0')
kivy.config.Config.write()


# Declare screens
class MenuScreen(Screen):
    pass

class SettingsScreen(Screen):
    pass

class NewsScreen(Screen):
    pass

class WeatherScreen(Screen):
    pass

class SmartHomeScreen(Screen):
    pass

class ScheduleScreen(Screen):
    pass

class CheckInScreen(Screen):
    pass

class WalkInScreen(Screen):
    pass

class WalkInDetailedScreen(Screen):
    pass

class PasswordQuitScreen(Screen):
    pass

class ConfirmQuitScreen(Screen):
    pass

class PasswordSettingsScreen(Screen):
    pass

class RoundedButton(Widget):
    def __init__(self, text, **kwargs):
        super().__init__(**kwargs)
        self.text = text
        self.size_hint = (1, 1)
        with self.canvas.before:
            Color(0.1, 0.5, 0.8, 1)
            self.rect = RoundedRectangle(size=self.size, pos=self.pos, radius=[20])
        self.bind(pos=self.update_rect, size=self.update_rect)

    def update_rect(self, *args):
        self.rect.size = self.size
        self.rect.pos = self.pos

class TestApp(App):
    # Properties for clock and weather display
    current_time = StringProperty("")
    current_date = StringProperty("")
    temperature_text = StringProperty("--°F")
    weather_icon_source = StringProperty("")
    
    # NetID input tracking (old, kept for compatibility)
    netid_input = StringProperty("")
    
    # N number input for check-in
    n_number_input = StringProperty("N")
    
    # Password inputs
    quit_password_input = StringProperty("")
    settings_password_input = StringProperty("")
    
    # Check-in status message
    checkin_status_text = StringProperty("No appointment now")
    
    # Walk-in status message
    walk_in_status_text = StringProperty("Next booking in 45 min")
    
    # Walk-in duration controls
    max_walk_in_duration = NumericProperty(120)
    walk_in_limit_reason = StringProperty("Limited by next reservation")
    walk_in_end_time = StringProperty("")
    
    # Detailed walk-in controls (hours/minutes)
    walk_in_hours = NumericProperty(0)
    walk_in_minutes = NumericProperty(30)
    walk_in_end_time_detailed = StringProperty("")
    
    # Button states
    walk_in_enabled = BooleanProperty(True)
    check_in_enabled = BooleanProperty(False)
    
    # Password (in production, hash this and store securely!)
    admin_password = os.environ.get("KIOSK_ADMIN_PW", "changeme")
    
    def __init__(self, **kwargs):
        super().__init__(**kwargs)
        # Initialize reservation manager
        self.reservation_manager = ReservationManager(
            room_name=CALENDAR_CONFIG['room_name'],
            credentials_file=CALENDAR_CONFIG['credentials_file'],
            calendar_id=CALENDAR_CONFIG['calendar_id']
        )
        # Initialize GPIO handler (will be None if not on Pi)
        self.gpio_handler = None
        self.focus_manager = None
        self.pir_handler = None
        self.led_handler = None
    
    def build(self):
        Builder.load_file('app.kv')
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

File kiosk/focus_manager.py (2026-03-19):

"""
Focus Manager for GPIO Button Navigation
Displays white border around currently focused widget
"""
from kivy.graphics import Line, Color, InstructionGroup
from kivy.clock import Clock
from kivy.logger import Logger


class FocusManager:
    """Manages focus highlighting for GPIO navigation"""
    
    # Define menu navigation grid
    MENU_GRID = {
        'quit': {'down': 'schedule', 'right': 'settings', 'up': None, 'left': None},
        'settings': {'down': 'walkin', 'left': 'quit', 'up': None, 'right': None},
        'schedule': {'up': 'quit', 'right': 'walkin', 'down': 'clock', 'left': None},
        'walkin': {'up': 'settings', 'down': 'checkin', 'left': 'schedule', 'right': None},
        'checkin': {'up': 'walkin', 'left': 'clock', 'down': None, 'right': None},
        'clock': {'up': 'schedule', 'right': 'checkin', 'down': None, 'left': None},
    }
    
    # Walk-in slider screen navigation
    WALKIN_GRID = {
        'slider': {'down': 'need_more_time', 'left': None, 'right': None, 'up': None},
        'need_more_time': {'up': 'slider', 'right': 'confirm', 'down': 'back', 'left': None},
        'confirm': {'up': 'slider', 'left': 'need_more_time', 'down': 'back', 'right': None},
        'back': {'up': 'need_more_time', 'left': None, 'right': None, 'down': None},
    }
    
    # Walk-in detailed screen navigation
    WALKIN_DETAILED_GRID = {
        'hour_minus': {'right': 'hour_plus', 'down': 'minute_minus', 'up': None, 'left': None},
        'hour_plus': {'left': 'hour_minus', 'down': 'minute_plus', 'up': None, 'right': None},
        'minute_minus': {'up': 'hour_minus', 'right': 'minute_plus', 'down': 'use_slider', 'left': None},
        'minute_plus': {'up': 'hour_plus', 'left': 'minute_minus', 'down': 'confirm_walkin', 'right': None},
        'use_slider': {'up': 'minute_minus', 'right': 'confirm_walkin', 'down': 'back', 'left': None},
        'confirm_walkin': {'up': 'minute_plus', 'left': 'use_slider', 'down': 'back', 'right': None},
        'back': {'up': 'use_slider', 'left': None, 'right': None, 'down': None},
    }
    
    # Schedule screen navigation
    SCHEDULE_GRID = {
        'back': {'up': None, 'down': None, 'left': None, 'right': None},
    }
    
    # Settings screen navigation
    SETTINGS_GRID = {
        'back': {'up': None, 'down': None, 'left': None, 'right': None},
    }
    
    # Confirm quit screen navigation
    CONFIRM_QUIT_GRID = {
        'yes': {'up': None, 'down': 'no', 'left': None, 'right': None},
        'no': {'up': 'yes', 'down': None, 'left': None, 'right': None},
    }
    
    def __init__(self, app):
        """Initialize focus manager
        
        Args:
            app: Reference to the Kivy app instance
        """
        self.app = app
        self.current_focus = 'checkin'  # Start on check-in button
        self.focus_widgets = {}
        self.focus_instruction = None
        
        # Schedule focus update to run after UI is built
        Clock.schedule_once(lambda dt: self.initialize_focus(), 1.0)
        
        # Bind to screen manager to automatically detect screen changes
        Clock.schedule_once(lambda dt: self.bind_to_screen_manager(), 1.1)
    
    def initialize_focus(self):
        """Initialize focus on the check-in button"""
        print("[FOCUS] Initializing focus system...")
        self.clear_focus()
        self.update_focus_list()
        print(f"[FOCUS] Setting initial focus to 'checkin' button")
        self.set_focus('checkin')  # Start on check-in
        print(f"[FOCUS] Focus initialization complete\n")
    
    def bind_to_screen_manager(self):
        """Bind to ScreenManager to automatically detect screen changes"""
        if hasattr(self.app, 'root') and hasattr(self.app.root, 'bind'):
            self.app.root.bind(current=self._on_screen_manager_change)
            print("[FOCUS] Bound to ScreenManager for automatic screen change detection")
    
    def _on_screen_manager_change(self, instance, value):
        """Called automatically when ScreenManager changes screens"""
        print(f"[FOCUS] Screen changed to: {value}")
        self.on_screen_change()
    
    def on_screen_change(self):
        """Called when screen changes - update focus"""
        Logger.info("FocusManager: Screen changed, updating focus")
        self.clear_focus()
        # Clear keyboard navigation state
        if hasattr(self, 'keyboard_buttons'):
            delattr(self, 'keyboard_buttons')
        if hasattr(self, 'current_focus_index'):
            delattr(self, 'current_focus_index')
        Clock.schedule_once(lambda dt: self.update_focus_list(), 0.2)
    
    def update_focus_list(self):
        """Update dictionary of focusable widgets based on current screen"""
        self.focus_widgets = {}
        current_screen_name = self.app.root.current
        
        try:
            current_screen = self.app.root.get_screen(current_screen_name)
        except:
            Logger.warning(f"FocusManager: Could not get screen {current_screen_name}")
            return
        
        if current_screen_name == 'menu':
            # Find actual widgets by walking the widget tree
            # First pass - log all widgets to understand structure
            def log_all_widgets(widget, depth=0):
                if depth > 15:
                    return
                widget_class = type(widget).__name__
                indent = "  " * depth
                text_info = ""
                if hasattr(widget, 'text'):
                    text_info = f" - text: {str(widget.text)[:30]}"
                Logger.info(f"{indent}{widget_class} at {widget.pos}{text_info}")
                if hasattr(widget, 'children'):
                    for child in widget.children:
                        log_all_widgets(child, depth + 1)
            
            Logger.info("=== Widget Tree ===")
            log_all_widgets(current_screen)
            Logger.info("=== End Widget Tree ===")
            
            def find_menu_widgets(widget, depth=0):
                if depth > 15:
                    return
                
                widget_class = type(widget).__name__
                
                # Look for specific button classes directly
                if widget_class == 'CheckInButton' and 'checkin' not in self.focus_widgets:
                    self.focus_widgets['checkin'] = widget
                    Logger.info(f"FocusManager: Found CheckInButton at {widget.pos}")
                
                elif widget_class == 'WalkInButton' and 'walkin' not in self.focus_widgets:
                    self.focus_widgets['walkin'] = widget
                    Logger.info(f"FocusManager: Found WalkInButton at {widget.pos}")
                
                # BigButtonTile detection - need to distinguish quit, settings, and schedule
                elif widget_class == 'BigButtonTile':
                    # Check text content to identify which button this is
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

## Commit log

2026-03-19 Initial commit: Dibs smart study room kiosk system
    [12mm Push Button Cap.3mf, Inner_Back.3mf, Inner_Base.3mf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]
2026-03-19 Add hardware photos, CAD renders, circuit diagrams, and documentation
    [Inner_Circuit_Final.fzz, Outer_Circuit_Final.fzz, Tinkercad_Inner Device.stl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]
2026-03-19 Update README images, remove outdated flowchart, add inner device photo
2026-03-19 Clean up Hardware section, use CAD renders only
2026-03-19 Stack circuit diagrams vertically for readability
